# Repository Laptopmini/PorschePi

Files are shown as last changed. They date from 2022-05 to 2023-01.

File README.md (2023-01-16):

# PorschePi

RaspberryPi based custom head unit for classic Porsche. Inspired by the [Porsche Classic Communication Management (PCCM)](https://shop.porscheusa.com/porscheoem/porsche_classic_/Highlights/porsche_classic_communication_management_pccm_91164559100.html) (91164559100), featuring a much larger touchscreen and the ability to use CarPlay wirelessly.

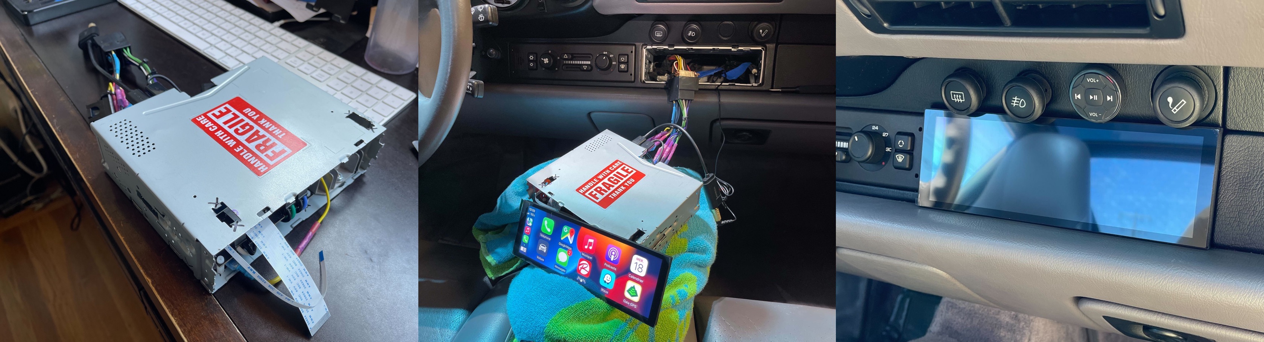
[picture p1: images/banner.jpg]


## General Information

In short, the goal was to create a single DIN head unit which fits in the rather restricted dashboard of classic Porsches without the need for any drilling, cutting or soldering (of the cabin), all the while making it look as OEM as possible. The results is a RPi 3 sandwiched between a Waveshare LCD controller and a Bang & Olufsen Hifiberry soundcard, with a graceful shutdown mechanism, powered USB hub, all fitted inside a removable single din unit.

### Key Features

- 7.9" Touchscreen
- Bang & Olufsen amplifier w/ 4 channel output
- Bluetooth remote for quick Play/Pause, Skip, Volume control
- Wireless CarPlay w/ Siri supported
- Porsche boot screen
- Porsche logo in CarPlay interface
- Porsche colored OAP interface (Black, Grey, Red)
- Graceful shutdown w/ 5 minute standby mode when ignition turn off
- 3D printed bezel

## Software

- [OpenAuto Pro v16](https://bluewavestudio.io/shop/openauto-pro-car-head-unit-solution/) ($29.99)
- [Plugin CarPlay Autobox for OpenAuto Pro](https://bluewavestudio.io/shop/plugin-carplay-autobox-for-openauto-pro/) ($9.00)
<!-- - [Plugin RTL-SDR for OpenAuto Pro](https://bluewavestudio.io/shop/plugin-rtl-sdr-for-openauto-pro/) ($6.00) -->

> TOTAL: $38.99

## Hardware

- [Raspberry Pi 3 Model B+](https://thepihut.com/products/raspberry-pi-3-model-b-plus?src=raspberrypi) ($35)
- [BeoCreate 4-Channel Amplifier](https://www.pishop.us/product/beocreate-4-channel-amplifier/) ($189.95)
- [Waveshare 7.9inch Capacitive LCD HDMI Display](https://www.amazon.com/7-9inch-Capacitive-LCD-HDMI-Resolution/dp/B087CNJYB4/) ($96.99)
- [SanDisk Extreme PRO microSDHC Memory Card Class 10](https://www.amazon.com/SanDisk-Extreme-microSDHC-Memory-Adapter/dp/B06XYHN68L/) ($13.23)
- [Carlinkit Wireless Carplay Dongle](https://www.amazon.com/Carlinkit-Wireless-Carplay-Android-Compatible/dp/B08FT73V87) ($58.99)
- [Powered USB Hub](https://www.amazon.com/Sabrent-Individual-Switches-Included-HB-UMP3/dp/B00TPMEOYM) ($18.99)
- [USB Microphone Adapter](https://www.amazon.com/UGREEN-External-Headphone-Microphone-Desktops/dp/B01N905VOY) ($13.99)
- [3.5mm TS to TRS](https://www.amazon.com/CablesOnline-2-Pack-Stereo-Adapters-AD-A37G-2/dp/B07787WMHG) ($5.95)
- [Bluetooth Media Remote Button](https://www.amazon.com/Wireless-Bluetooth-Motorcycle-Steering-Bracket/dp/B081RG3NKC) ($17.99)
- [GPIO Female to Female Jumper Wires](https://www.amazon.com/dp/B09FP1WF8Q) ($5.99)
- [12v 16AWG Cables (5ft/Color)](https://www.amazon.com/Fermerry-Silicone-Stranded-Automotive-Electronic/dp/B089CPH72F?th=1) ($15.62)
- [12v Timer Relay](https://www.amazon.com/Timer-CONFIGURABLE-CYCLING-OPTIONAL-TRIGGER/dp/B083HN673G/) ($34.99)
- [12v to 5v Stepdown](https://www.amazon.com/Regulator-Converter-12V-Waterproof-Transformer/dp/B09SD9SH8C) ($13.99)
- [SPDT Relays](https://www.amazon.com/Pack-EPAuto-Relay-Harness-Bosch/dp/B072QXDZRD/) ($10.97)
- [Heatshrink Crimp Connectors](https://www.amazon.com/TICONN-Connectors-Waterproof-Electrical-Automotive/dp/B08NWBRV4K) ($9.99)
- [T-Tap Wire Connectors](https://www.amazon.com/dp/B07XMJ5KTY) ($9.95)
- [Nylon Standoffs](https://www.amazon.com/dp/B07DPPNBFN) ($12.89)
- [Heatshrink Tubbing](https://www.amazon.com/560PCS-Heat-Shrink-Tubing-Eventronic/dp/B072PCQ2LW/) ($6.99)
- [6-Pin Ribbon Cable](https://www.amazon.com/dp/B07S19M2G1) ($6.69)
- [6-Pin Extension Connector](https://www.amazon.com/dp/B07RWNDFV1) ($7.99)
- [40-Pin Ribbon Cable](https://www.amazon.com/dp/B09CL53KZF) ($6.90)
- [Heatsinks](https://www.amazon.com/dp/B08N68V2N9) ($4.59)
<!-- - [FM Radio RTL-SDR USB Adapter](https://www.amazon.com/NooElec-NESDR-Smart-Enclosure-R820T2-Based/dp/B01HA642SW) -->

> TOTAL: $598.63

## Tools

- USB Keyboard & Mouse for setup
- DC 5V 3A Power Supply for Pi setup
- [DC 12V 5A Power Supply for Amplifier setup](https://www.amazon.com/ALITOVE-Adapter-Converter-100-240V-5-5x2-1mm/dp/B01GEA8PQA/)
- Power Drill
- Dremel Tool
- [Heat Gun](https://www.amazon.com/Portable-Handheld-Crafts-Embossing-Wrapping/dp/B08Z3GQN6X/)
- Wire Stripers
- [Crimping Tool](https://www.amazon.com/dp/B07S4HDGK9)

> The cost of tools was omitted as most were owned, borrowed or will remain after this project.

## Cost

> TOTAL: $637.62
>
> TARGET: < $1,350.10

## Resources

### BlueWave Studio

- [Supported Keystrokes](https://bluewavestudio.io/community/thread-2048.html)
- [Graceful delayed shutdown example](https://bluewavestudio.io/community/thread-1128.html)

### HiFiBerry BeoCreate

- [Setup Instructions](https://www.hifiberry.com/docs/software/configuring-linux-3-18-x/)
- [Documentation](https://www.hifiberry.com/beocreate/beocreate-doc/)
- [Support Forums](https://support.hifiberry.com/hc/en-us/community/topics/115000377385-DSP-boards-and-Beocreate)
- [Repo](https://github.com/hifiberry/hifiberry-os)
- [DSP Toolkit](https://github.com/hifiberry/hifiberry-dsp/blob/master/doc/dsptoolkit.md)

### WaveShare

- [Documentation](https://www.waveshare.com/wiki/7.9inch_HDMI_LCD)

### Timers Shop

- [Website](http://timers.shop/6V-28V-10-Amp-Timer-Wi-Fi-configurable-via-phone_p_44.html)
- [Documentation](https://timers.shop/assets/documentation/Multifunctional_Timer_Wifi.pdf)
- [Configuration Video](https://www.youtube.com/watch?v=wqbvz5oopu0&feature=emb_title)

## Setup

For the following instructions, connect a regular display and use a keyboard & mouse until you have completed the `Waveshare Touchscreen` step.

### OpenAuto

- [Flash](https://www.balena.io/etcher/) your `openauto-pro-16.0.zip` image to the SD card
- Remount & run `sh copy_helpers.sh /Volumes/boot/`
- Insert the SD Card into the Pi, and boot up the setup
- Use `1`, `2`, `UP`, `DOWN` and `ENTER` keys to work your way through the wizard

### Autobox (CarPlay)

- Once on the main screen, select `Autobox`, and `Browse`
- Go to `/boot/porschepi/` and select `openauto_autobox_plugin.zip`
- Then select `Enter serial...`, and use your plugin license key
- Select `Finish`, and from your iPhone, connect the the bluetooth device named `AutoKit-****`
- Wait for it to associate the wifi network, at which point the interface should appear
- Within CarPlay, select `Car` to return to OpenAuto

### Pi Settings

- Use [Power] -> [Exit] to reach the Pi's desktop
- Go through the "Welcome to Raspberry Pi" setup but ignore the "Set Up Screen" step for now, do NOT update packages
- Make sure SSH is enabled under the Raspberry Pi Configuration, use the command `ifconfig` to make note of the Pi's assigned IP on the network
- Under `Preferences` -> `Appearance Settings`, change the wallpaper to `/boot/porschepi/splash.png` and invert the Menu Bar's colors
- Under `Preferences` -> `Raspberry Pi Configuration`, change the hostname to `Porsche`
- Execute `cd /boot/porschepi && sudo sh apply_configs.sh` and wait for the Pi to power down

### WaveShare Touchscreen

- Connect the Waveshare touchscreen and restart the Pi
- If you still need to adjust your screen orientation, do the following
  - [Power] -> [Exit] out of OpenAuto
  - Go to `Screen Configuration`, `Configure`, `Screens`, `HDMI-1`, `Orientation`
  - Using the "Rotate Touch" button behind the screen, press until you see a green flash to rotate the touch. Repeat as necessary.

### Bluetooth Remote

- Press any button on the bluetooth remote, it should start blinking
- From the Pi's desktop, go to `Preferences` -> `Bluetooth Manager`
- In the list of devices, select `Jetion remote v2.0`
- Under `Device`, select `Pair` then `Trust`

### BeoCreate

- Refer to `beocreate/docs/jumpers.png` and remove jumper 4 & 5 on the Beocreate HAT.
- Refer to `beocreate/docs/connectors.png` to know how to wire in the soundcard to your speakers
- Connect the Pi to the BeoCreate HAT and power it up using the 12v input
- Lower the volume in OpenAuto (or from the Pi's Sound Preferences) to avoid damaging your speakers when first testing
- Execute `cd /boot/porschepi/beocreate && sudo sh setup.sh`

### Create a Backup

- Make an image of your SD card using `sudo dd bs=4m if=/dev/disk2 of=builds/porschepi-X.Y.Z.img`
- Reflash this image anytime to a similar sized SD card to restore this setup

## Assembly

### Diagram

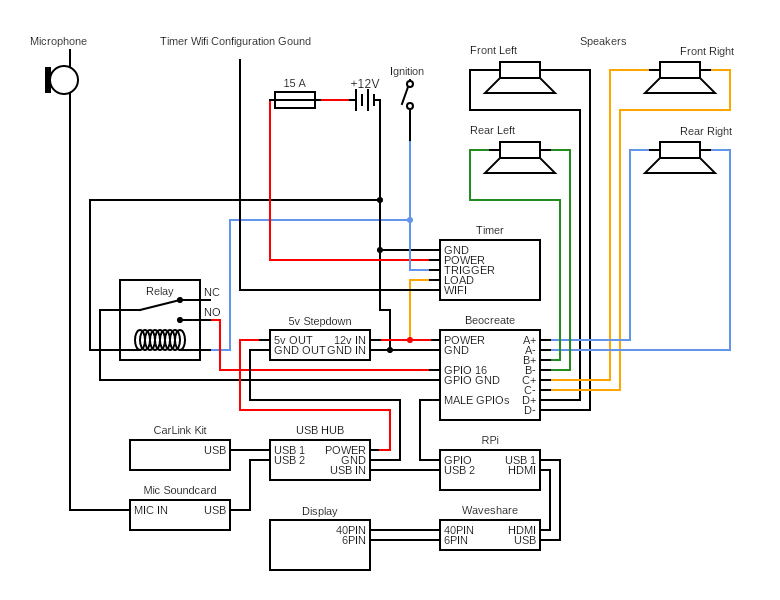
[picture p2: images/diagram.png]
PorschePi Diagram (https://www.circuit-diagram.org/editor/c/6b1c75bd69934876a32e00b4504df468)


### Form

First, you need to separate the screen from its PCB carefully using a knife. I recommend you disconnect its ribbons and tape them safely out of the way to avoid damaging them. Once done, upgrade to the longer ribbons to provide more working room between the board and display.

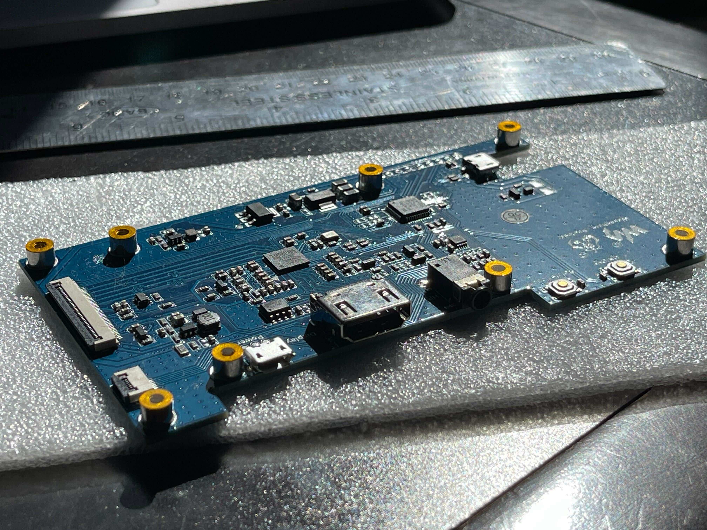
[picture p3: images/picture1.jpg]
Picture of separated PCB


I recommended you bench test components independently before mounting them. Keep in mind to space out components which produce heat, such as the PCB stack from other parts. Use heatsinks to help dissipate the heat from the PCB stack.

For the timer, temporarily wire it to a power source according to the previous schematics, and ground the white wire while you power it on to enable wifi configuration. Connect to its network and visit the IP listed on the timer. Import the configuration `timer/configuration.bin`, or set it to Function 12 with a timer t1 of 5 minutes and trigger value of 2. As seen in the diagram, its recommended you make this configuration wire output from your unit; you can then add a T-tap (or similar) to your ground wire to easily connect it at any time to make adjustments to its configuration.

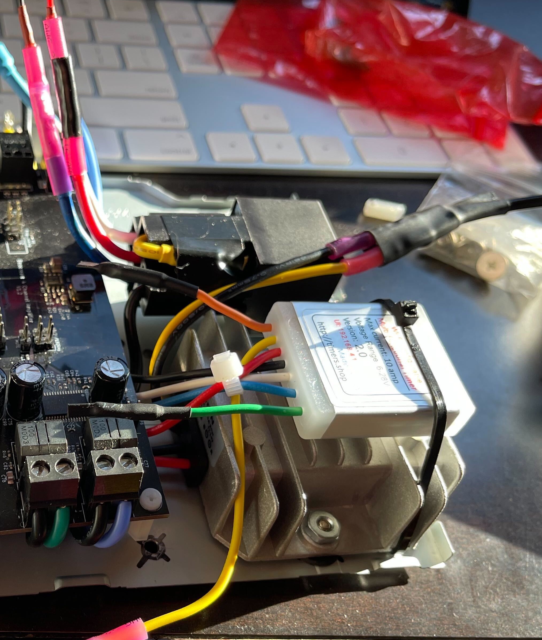
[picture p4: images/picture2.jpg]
Picture of timer wired in


To test or wire in the automotive relay (to monitor the state of the ignition), enable the power monitoring by setting `POWER_MONITOR_ENABLED=1` in `/boot/porschepi/settings.conf`. When ignition is cutoff, the screen and sound is turned off during a grace period at the end of which the system is shutdown. If ignition is restored, the screen and sound are re-enabled and any shutdown canceled. The script is setup to use GPIO / BCM 16 - physical pin 32 on Beocreate GPIO. This allows the use of the neighboring ground on pin 34, as seen below.

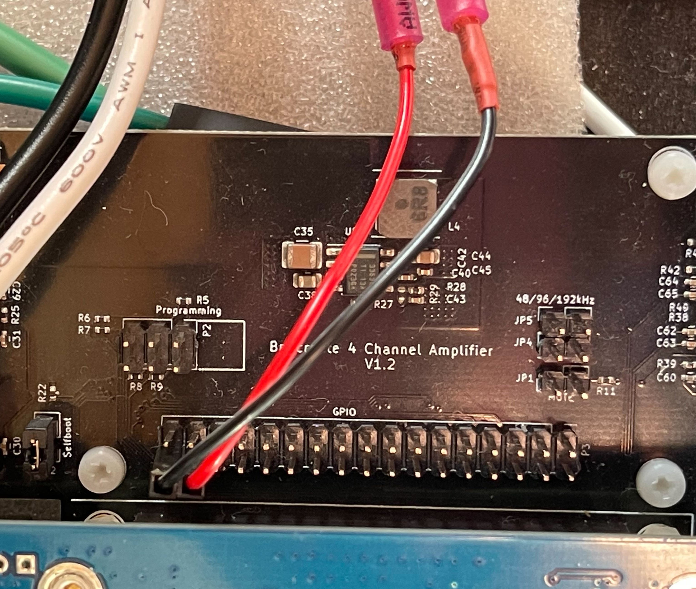
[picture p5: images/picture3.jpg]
Picture of relay wired in


### Fit

As with the PCCM, one of the goals of this project is to fit into a standard single DIN format. After finding an old unit, take it apart and gut out its components to reuse the shell as a donor for your new hardware.

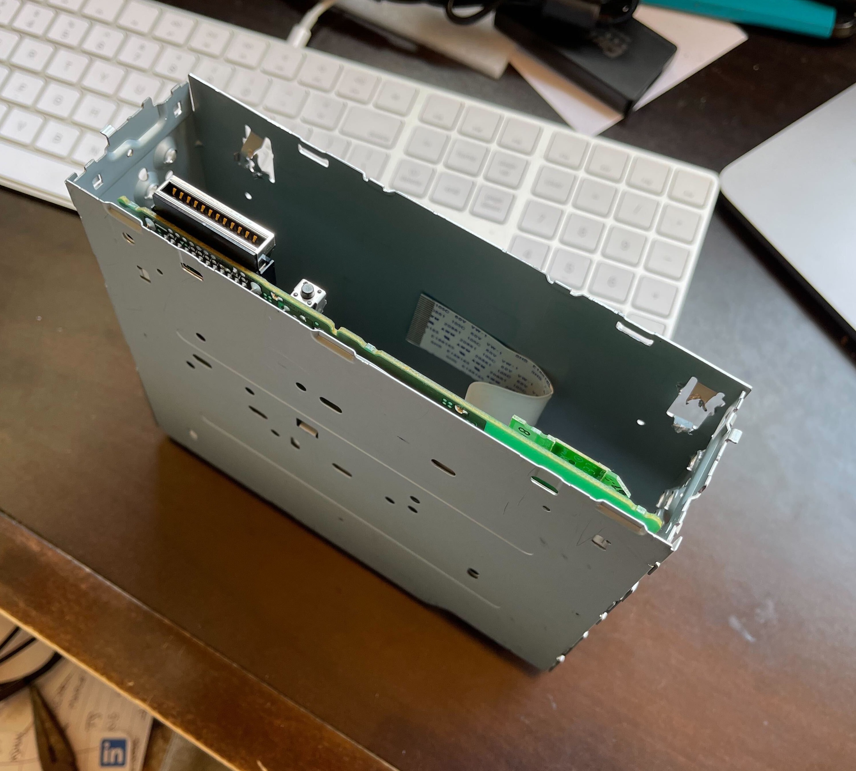
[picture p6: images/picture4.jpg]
Picture of shell


Using the previously mentioned diagram, arrange the components within the shell accordingly. Using a Dremel tool, you can clean up mounting points and cut out any conflicting parts of the shell.

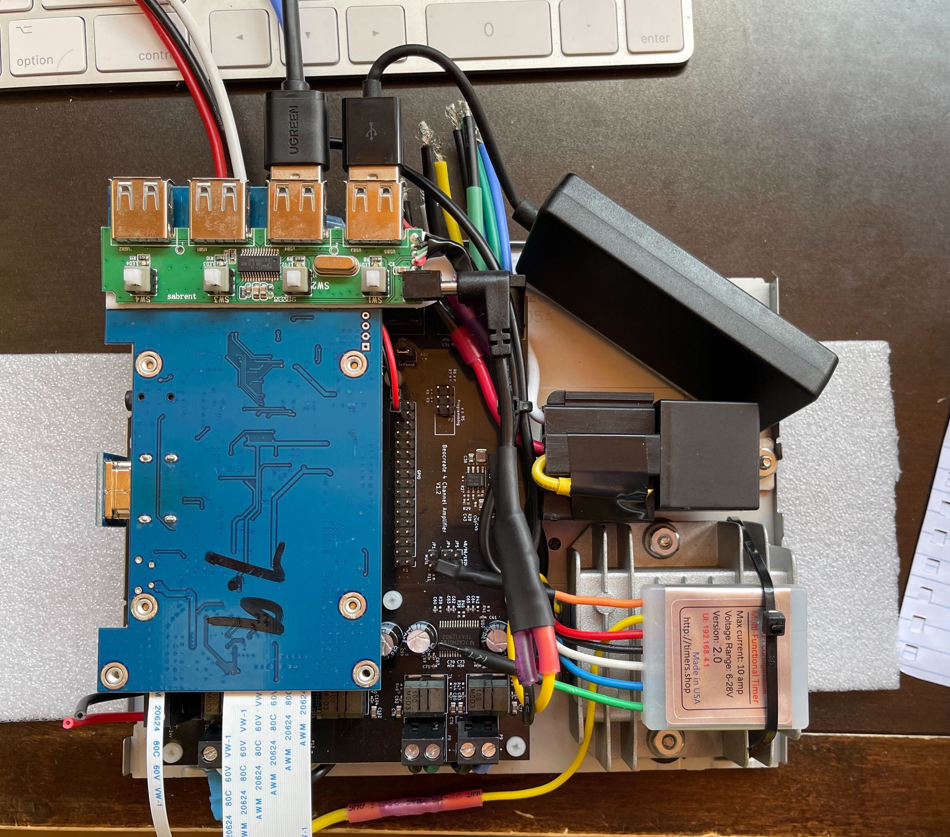
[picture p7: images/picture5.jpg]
Picture of shell with all components mounted in


Once the unit is completed, wire it into the harness used to connect the head unit to the car. Optionally, you can add a 15AMP fuse onto the positive power input to insulate your unit from other components relying on your vehicle's existing fuse.

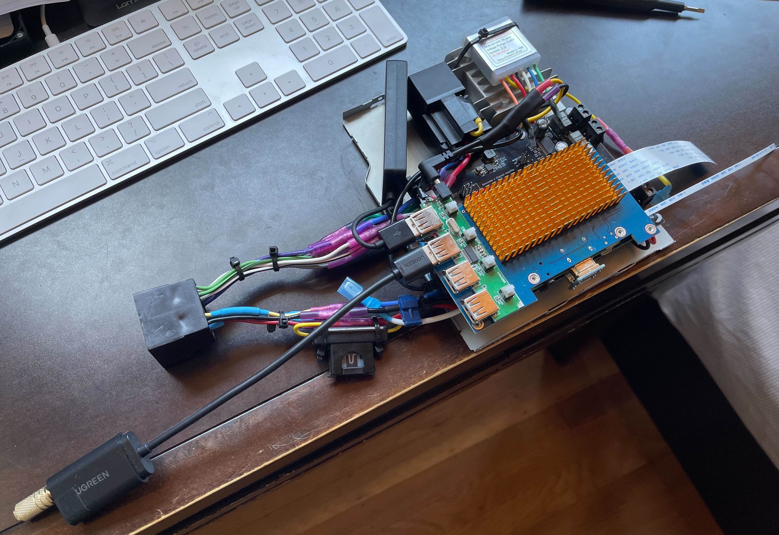
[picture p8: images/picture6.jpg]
Picture of harness wired in


### Finish

As a safety measure, remove the fuse corresponding to the head unit in your car, then connect the harness before reapplying the fuse. Verify that all functions are working before proceeding with inserting the unit into the dashboard.

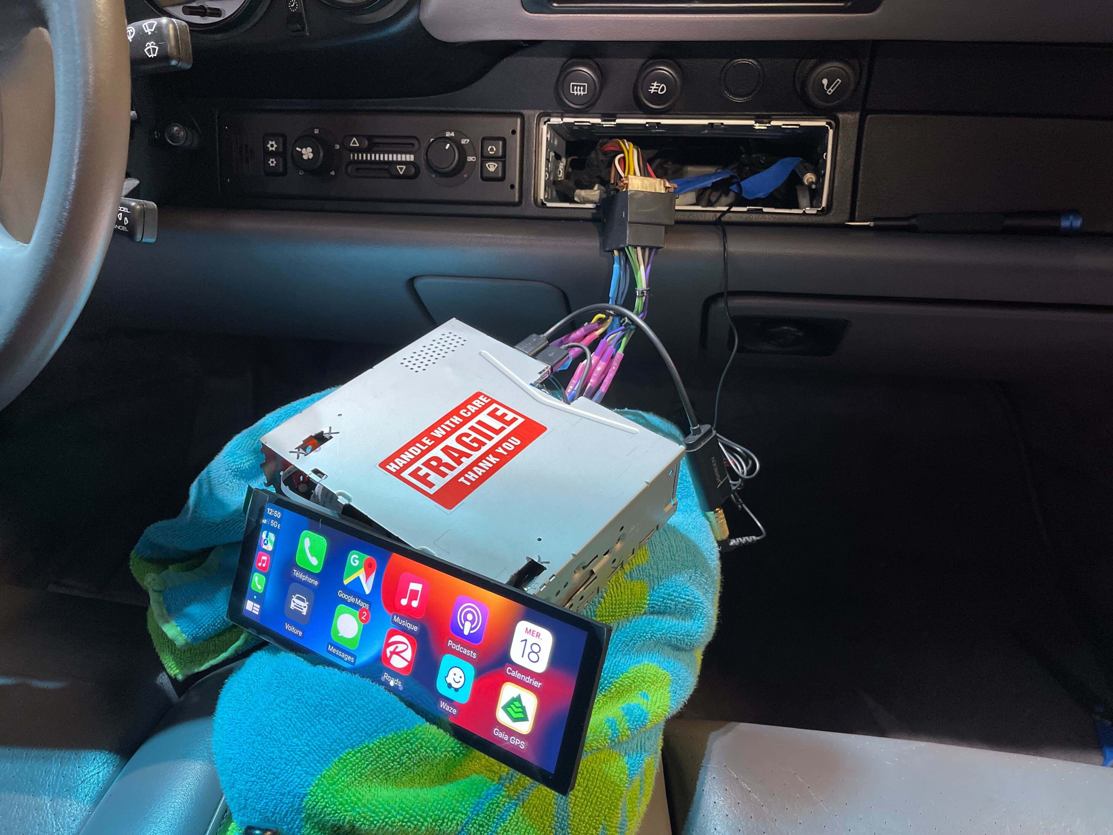
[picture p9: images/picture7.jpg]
Picture of unit testing in car


If you run into issues, check out the Troubleshooting section below for some common issues. Once you've verified your setup, insert the unit into the dashboard carefully, making sure wires behind it are clearing any obstructions and not getting pinched. You can access the back of the unit through the underside of the dashboard. Don't forget to mount the bluetooth remote as well.

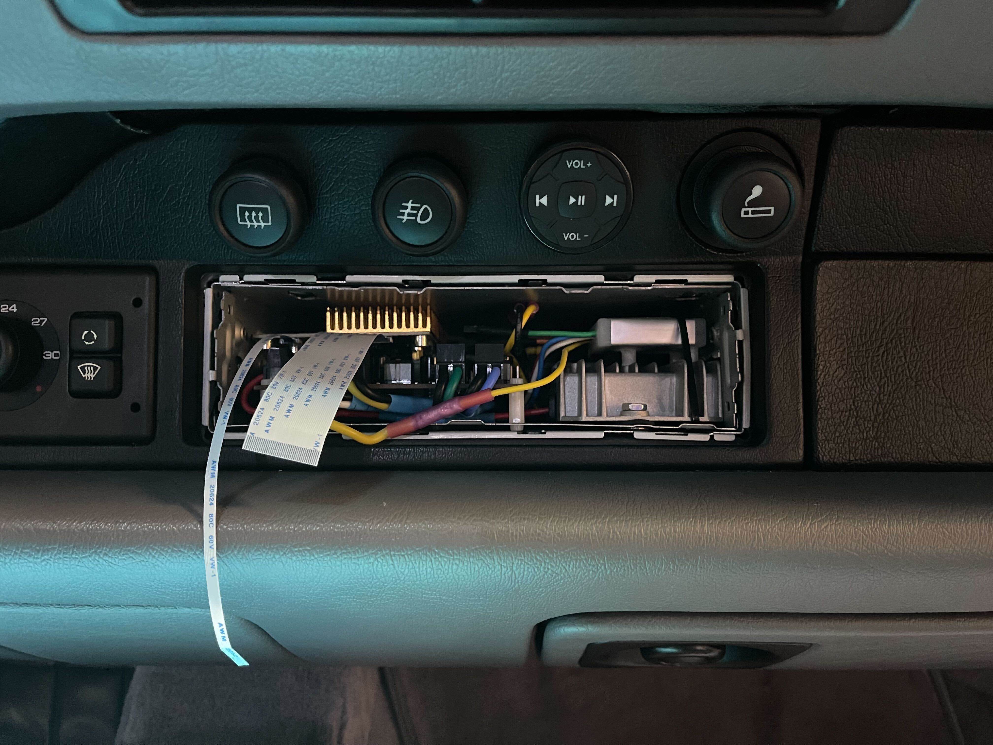
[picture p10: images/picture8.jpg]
Picture of unit in car


Given my limited experience with 3D printing, I enlisted the help of a friend to design and print a bezel for the screen with mounting tabs to secure it to the dashboard. Use the `waveshare/bezel.STL` file to print your own copy. If you don't own a 3D printer, I recommend using an online printing service.

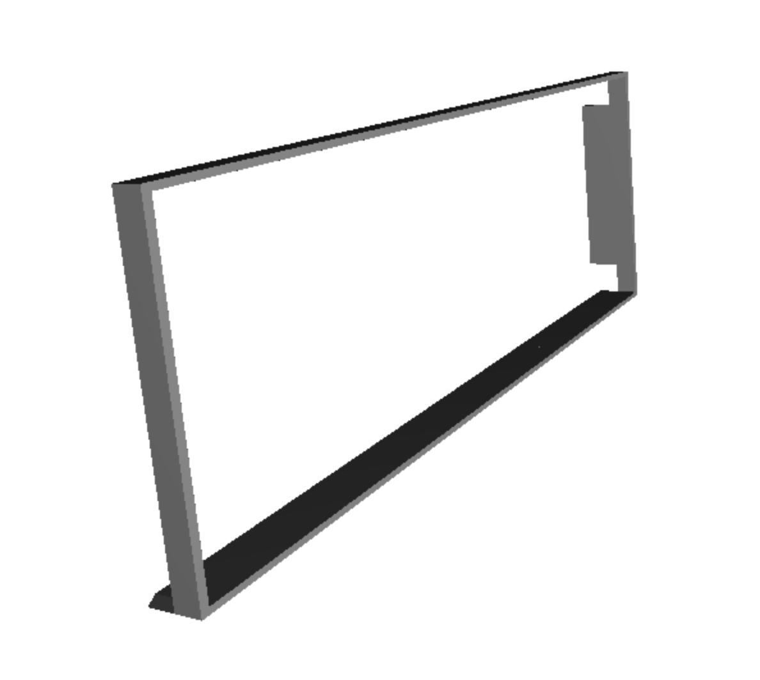
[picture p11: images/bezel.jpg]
3D Printed Bezel


Insert the screen into the 3D printed bezel and then push its tabs into the slits of the dashboard to securely mount it. Make sure the first insert the top then bottom, as to clear the instrument knobs located above the head unit.

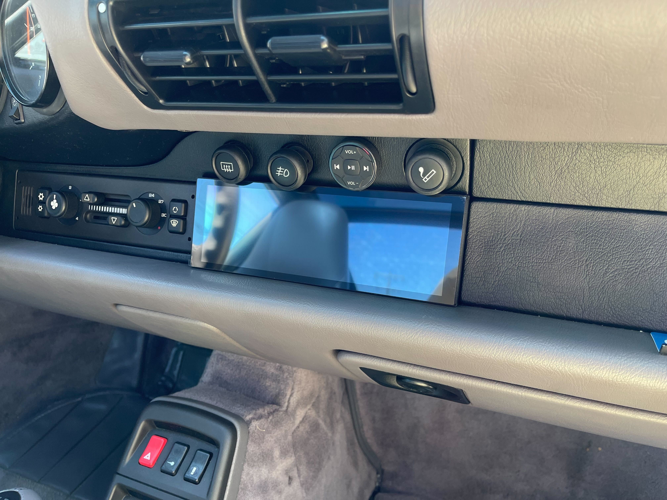
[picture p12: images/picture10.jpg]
Picture of screen mounted


## Troubleshooting

### System Logs

You can find logs for OpenAuto under `/home/pi/.openauto/cache/openauto.log`.

### CarPlay

If you need to reset your CarPlay connection on your device, go to Settings.app, and forget both Bluetooth and Wifi networks for `AutoKit-****`. Then reconnect via bluetooth to re-initiate the pairing process.

### Display

If you see black borders around the screen, try disabling `disable_overscan=1` and adapting the `overscan_*` properties in `/boot/config.txt`.

### Splash

To make a new splash screen based on a sequence of 24 images use the following command:

```bash
ffmpeg -r 24 -f image2 -s 1280x400 -i rpi/splash_%01d.png -start_number 1 -vframes 24 -vcodec libx264 -crf 25 -pix_fmt yuv420p splash.h264
sudo cp -f ~/splash.h264 /usr/share/openautopro/splash1.h264
sudo cp -f ~/splash.h264 /usr/share/openautopro/splash2.h264
```

### Custom Keys

To add keymaps, use `DISPLAY=:0.0 xev` to find the correct keycode and add mappings to `/boot/porschepi/restore-settings.sh` using `xmodmap`.

### Volume

To change the default volume of the amplifier (not the default software volume), change the value of `VOLUME` in `/boot/porschepi/settings.conf`. Adjust this according to what your speakers can handle.

When using the Bluetooth Remote, if the volume is lowered or raised too fast repetitively, the left and right channel can become unbalanced (different volume) due to a bug. If this occurs, use the "Reset Volume" application in OpenAuto.

### Power Monitor

If you run into issues with the power monitoring service, you can check its status using `systemctl status power-monitor.service` or disable its operation using `POWER_MONITOR_ENABLED=0` in `/boot/porschepi/settings.conf`. To check the service's logs run `journalctl -u power-monitor.service` and use `POWER_MONITOR_DEBUG=1` to make it print out debug statements.

If you ever make changes to the Timer's power cutoff timing, make sure to adjusts the `SHUTDOWN_DELAY` accordingly in `/boot/porschepi/power-monitor.py`. The value of `SHUTDOWN_DELAY` should always be smaller than that of the timer, with enough time to allow for a graceful shutdown before power is cutoff.

## Omitted Components

Here is a list of components which were considered at some point but omitted in the end for one reason or another:

- [Raspberry Pi 4 Model B 2019 Quad Core 64 Bit WiFi Bluetooth (4GB)](https://www.amazon.com/Raspberry-Model-2019-Quad-Bluetooth/dp/B07TC2BK1X)
  - Unable due to shortage
- [CarPiHat](https://thepihut.com/products/carpihat-car-interface-hat-for-raspberry-pi?variant=41600908492995)
  - Incompatible with 4-Channel Amplifier HAT
- [ELM327 OBD to USB Adapter](https://www.amazon.com/gp/product/B083FML519/)
  - Poor access to OBD in car, impractical with little reward

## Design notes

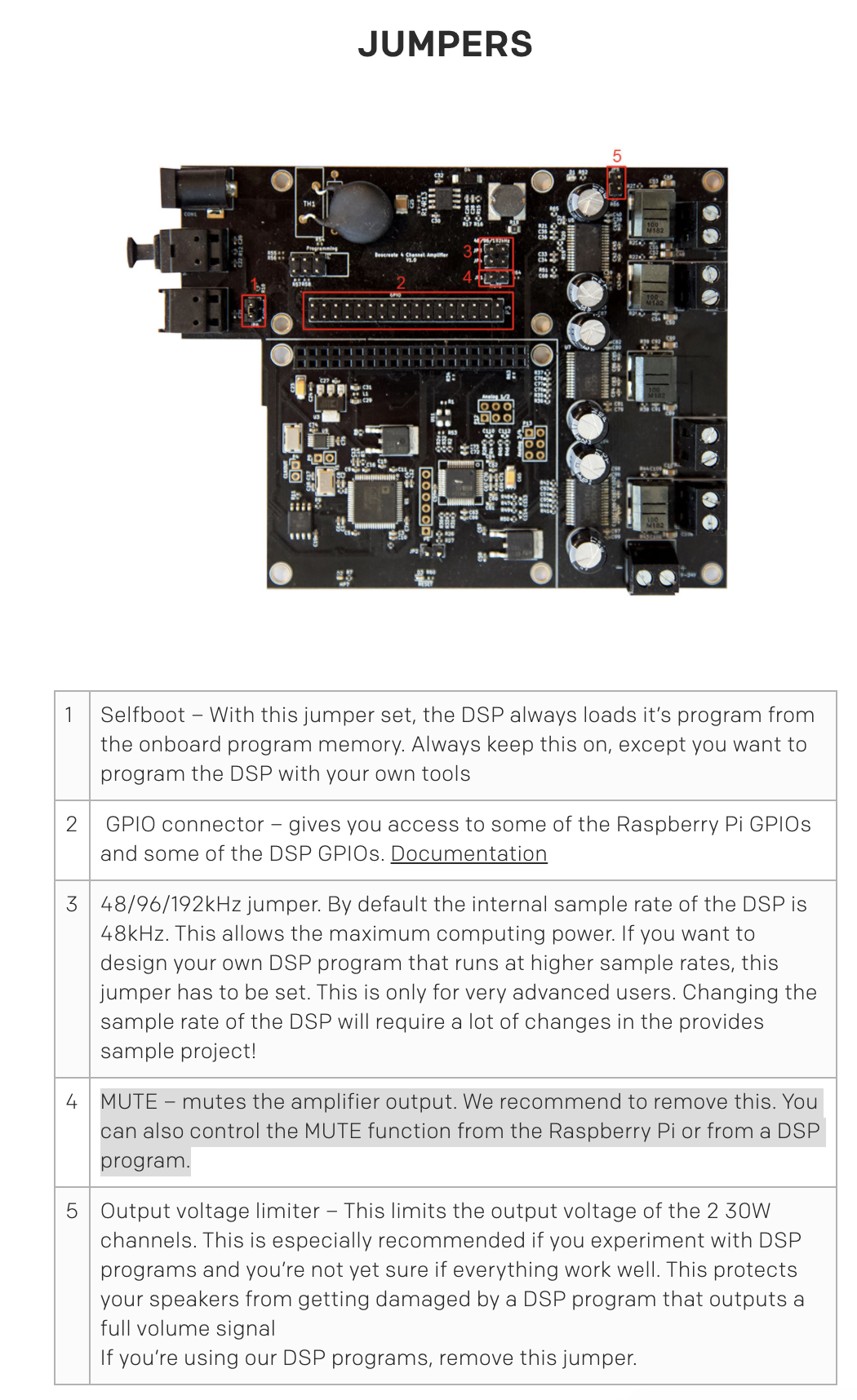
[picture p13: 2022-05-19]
beocreate/docs/jumpers.png

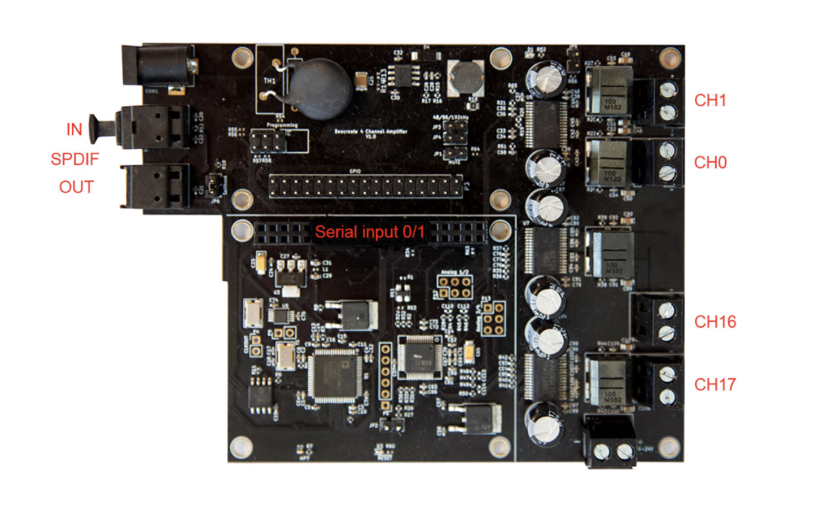
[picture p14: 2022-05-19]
beocreate/docs/dspchannels.png

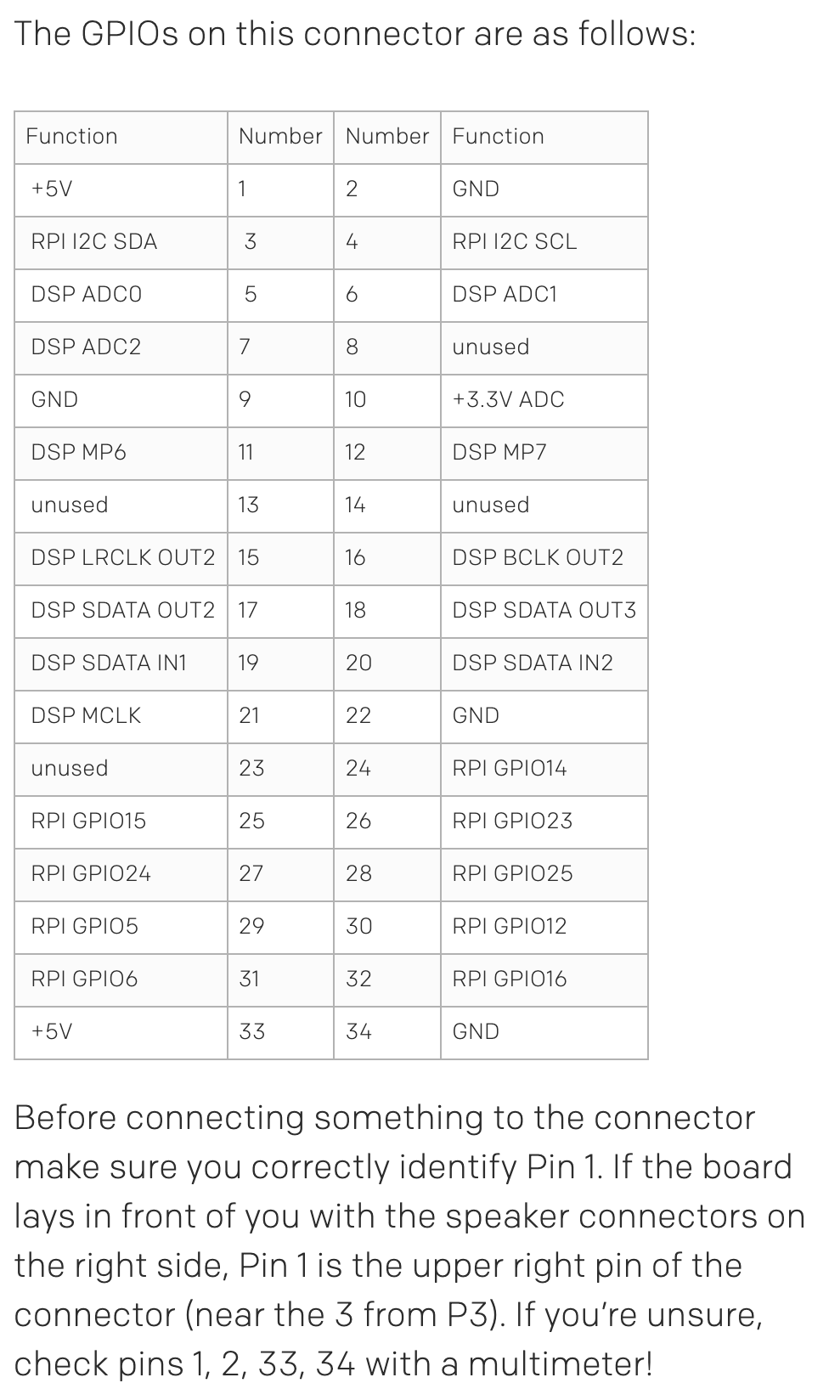
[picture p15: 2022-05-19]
beocreate/docs/available-gpio.png

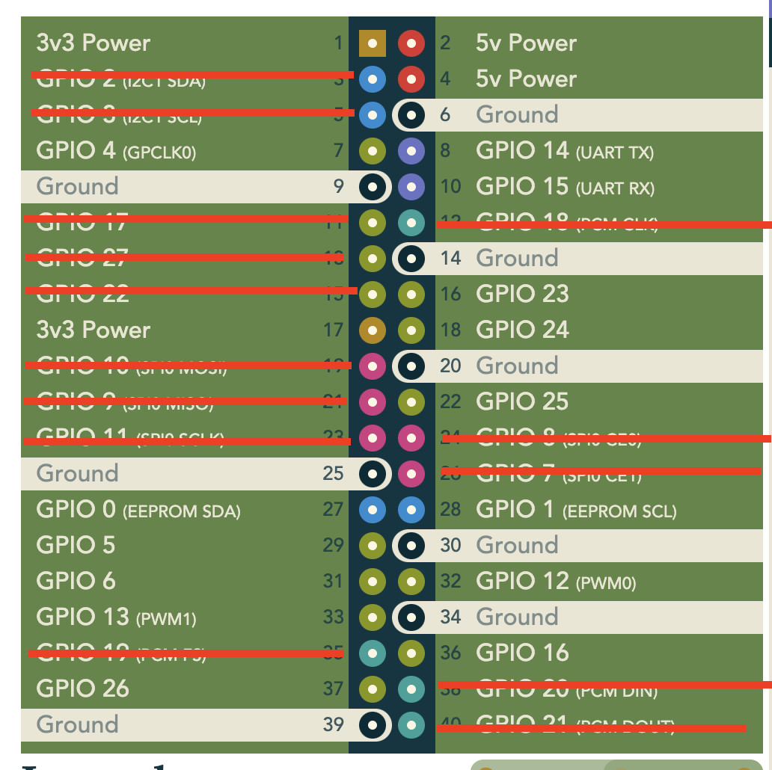
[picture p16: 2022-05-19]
beocreate/docs/available-gpio-pi.png

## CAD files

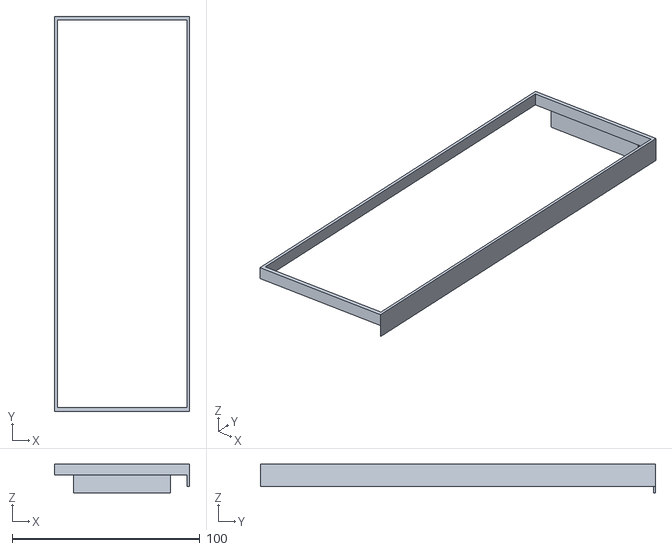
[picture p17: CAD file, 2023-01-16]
waveshare/bezel.STL
71.9 x 210.3 x 15.4

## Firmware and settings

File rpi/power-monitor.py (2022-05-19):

#!/usr/bin/python3 -u
# Source: https://bluewavestudio.io/community/thread-1128.html
# This script was originaly written by 765GHF, many thanks to them.

import os
import RPi.GPIO as GPIO
import subprocess
import sys
import time
from dotenv import load_dotenv

# Configuration File
CONF = "/boot/porschepi/settings.conf"

# Load configuration
load_dotenv(CONF)

if not int(os.getenv("POWER_MONITOR_ENABLED", "0")):
	print("Power monitoring disabled in " + CONF + ". Terminating.")
	sys.exit() 

# Enable debug verbose output
DEBUG = int(os.getenv("POWER_MONITOR_DEBUG", "0"))

# GPIO / BCM 16 - physical pin 32 on Beocreate
PORT = 16

# Shutdown delay in seconds (4.5 mins)
SHUTDOWN_DELAY = 270

# Number of seconds after ignition returns to cancel shutdown
CANCEL_SHUTDOWN = 5

# specify pin numbering format
GPIO.setmode(GPIO.BCM)

# set pin to input, set pull up resistor so it reads high
GPIO.setup((PORT), GPIO.IN, pull_up_down=GPIO.PUD_UP)

IGN_STATUS = 1
SHUTDOWN = 0
IGN_OFF_TIME = 0
IGN_OFF_LAST_SEEN = 0
NOW = 0

def setDisplayEnabled( on ):
	ARG = "on"
	if not on:
		ARG = "off"
	try:
		subprocess.run("XAUTHORITY=/home/pi/.Xauthority xset -display :0.0 dpms force " + ARG, shell=True)
	except subprocess.CalledProcessError as displaycmd:
		print("Turning ", ARG, " display failed with error code: ", displaycmd.returncode)
	return

def setSoundEnabled( on ):
	CMD = "unmute"
	if not on:
		CMD = "mute"
	try:
		subprocess.run(["/opt/hifiberry/bin/" + CMD + "-beocreate"])
	except subprocess.CalledProcessError as soundcmd:
		print("Attempt to ", CMD, " sound failed with error code: ", soundcmd.returncode)
	return

# Make sure Sound & Display are enabled
setSoundEnabled(True)
setDisplayEnabled(True)

while True:
	NOW = time.time()

	# Get the status of the ignition
	IGN_UP = GPIO.input(PORT)
 
	# Ignition switched off? Then set shutdown flag and igntion off time
	if not IGN_UP and not SHUTDOWN:
		print("Ignition switched off, setting shutdown flag!")
		SHUTDOWN = 1
		IGN_OFF_TIME = NOW
		setSoundEnabled(False)
		setDisplayEnabled(False)

	# Increment this counter while ignition is off
	if not IGN_UP and SHUTDOWN:
		IGN_OFF_LAST_SEEN = NOW

	# If ignition is off, check if shutdown delay time reached
	if (SHUTDOWN and not IGN_UP and ((NOW - IGN_OFF_TIME) > SHUTDOWN_DELAY)):
		print("Shutdown delay of", SHUTDOWN_DELAY, "seconds reached, shutting down!")
		try:
			subprocess.check_output(["shutdown", "-h", "now", "--no-wall"])
		except subprocess.CalledProcessError as shutdowncmd:
			print("Shutdown failed with error code: ", shutdowncmd.returncode)
			break
	
	# Cancel shutdown if power has been back for CANCEL_SHUTDOWN seconds
	if ((NOW - IGN_OFF_LAST_SEEN) >= CANCEL_SHUTDOWN ) and SHUTDOWN:
		print("Ignition has been back for ", CANCEL_SHUTDOWN, " seconds, shutdown flag reset.")
		SHUTDOWN = 0
		IGN_OFF_TIME = 0
		IGN_OFF_LAST_SEEN = 0
		setSoundEnabled(True)
		setDisplayEnabled(True)

	if DEBUG:
		STATUS = GPIO.input(PORT)
		print("Pin status is: ", STATUS)
		print("IGN_UP is set to: ", IGN_UP)
		print("SHUTDOWN is set to: ", SHUTDOWN)
		if SHUTDOWN:
			print("Igntion off time is: ", IGN_OFF_TIME)
			print("Igntion off last seen time is: ", IGN_OFF_LAST_SEEN)
			print("Current time is: ", NOW)
			print("Elapsed time is: ", (NOW - IGN_OFF_TIME))

	time.sleep(1)

if DEBUG:
	print("Exiting")

GPIO.cleanup()

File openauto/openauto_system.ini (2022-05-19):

[Units]
ConsumptionUnit=0
DistanceUnit=0
TemperatureUnit=1
[Appearance]
TimeFormat=0
ShowTopBarInAndroidAuto=true
ShowTemperature=false
ShowClockInMirroring=true
ShowClockInAutobox=false
ShowClockInAndroidAuto=true
ControlsOpacity=75
FontScale=0
Language=English
ObdBarDisplayMode=1
ShowClock=true
TileStyle=0
[System]
AndroidAutoAutostart=true
TouchscreenType=1
ScreenType=1
ScreenSplitPercentage=30
DownloadCoverart=true
[Mirroring]
ShowTopBarInMirroring=true
ResolutionWidth=1280
ResolutionHeight=400
[Autobox]
ShowTopBarInAutobox=false
ScreenDPI=160
Name=Autobox-OAP
OemName=Porsche
AutomaticWirelessConnection=true
WorkMode=2
VendorId=4884
ProductId=5408
[DayNight]
OpenAutoDayNightControllerType=2
AndroidAutoDayNightControllerType=2
AutoboxDayNightControllerType=2
SunriseTime=6:0
SunsetTime=18:0
LightSensorThreshold=100
LightSensorDescriptor=/dev/i2c-3
LightSensorAddress=57
LightSensorMinRange=0
LightSensorMaxRange=30000
OpenAutoDayNightMode=1
AndroidAutoDayNightMode=2
AutoboxDayNightMode=2
GpioPin=1
[Day]
WallpaperPath=
WallpaperMode=0
WallpaperOpacity=100
BackgroundColor=#4b4b4b
HighlightColor=#1f85ff
ControlBackground=#e2e2e2
ControlForeground=#1f85ff
NormalFontColor=#000000
SpecialFontColor=#000000
DescriptionFontColor=#202020
BarBackgroundColor=#b2b2b2
ControlBoxBackgroundColor=#808080
GaugeIndicatorColor=#f5b42a
IconShadowColor=#60000000
IconColor=#000000
SideWidgetBackgroundColor=#b2b2b2
BarShadowColor=#333333
[Night]
WallpaperPath=
WallpaperMode=0
WallpaperOpacity=100
BackgroundColor=#4b4b4b
HighlightColor=#d5001c
ControlBackground=#000000
ControlForeground=#d5001c
NormalFontColor=#ffffff
SpecialFontColor=#d5001c
DescriptionFontColor=#888888
BarBackgroundColor=#000000
ControlBoxBackgroundColor=#181818
GaugeIndicatorColor=#d5001c
IconShadowColor=#80000000
IconColor=#ffffff
SideWidgetBackgroundColor=#000000
BarShadowColor=#333333
[General]
HandednessOfTraffic=0
ShowClock=true
HasTouchscreen=true
TemperatureSensorDescriptor=
[Video]
FPS=2
Resolution=1
ScreenDPI=140
MarginWidth=0
MarginHeight=0
ProjectionOrientation=3
[Audio]
MusicAudioChannelEnabled=true
SpeechAudioChannelEnabled=true
SplashFilePath=
PhoneNotificationFilePath=
RingtoneFilePath=
VolumeStep=1
MixerName=
MuteMixerName=
Autoplay=false
MediaStorageMusicVolumeLevel=100
[Bluetooth]
AdapterType=0
RemoteAdapterAddress=
[Obd]
ObdAdapterStartupSequence=ATZ;ATE0;ATS0;ATL0;ATH0;ATSP0
ObdAdapterDescriptor=
ObdAdapterBaudrate=115200
ObdProbePeriod=5
ObdDeviceType=0
ObdAdapterRfCommAddress=
ObdAdapterRfCommChannel=1
ObdMaxNoDataResponseCount=20
[RearCamera]
DeviceDescriptor=v4l2:///dev/video0
GpioPin=0
ShowGuideLine=false
Orientation=0
ScriptPath=
BackendType=0
ResolutionWidth=1280
ResolutionHeight=400
ViewFinderIndex=0
VolumeLevelEnabled=false
VolumeLevel=70
[Gestures]
VolumeGestureEnabled=0
SensorDescriptor=
Enabled=false
InactivityTimeout=0
SensorOrientation=3
NextTrackGestureEnabled=true
PreviousTrackGestureEnabled=true
AnswerCallGestureEnabled=true
HangUpCallGestureEnabled=true
VolumeUpGestureEnabled=true
VolumeDownGestureEnabled=true
TogglePlayGestureEnabled=true
[Wireless]
HotspotEnabled=false
Enabled=false
Ssid=Porsche
Bssid=
Key=993
Port=5000
HotspotBand=0
[Media]
DefaultStoragePath=/media
[Api]
EndpointListenPort=44405
MaxClients=3
[FM]
BandwithType=0
SquelchLevel=350
SquelchLimit=10

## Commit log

2022-05-19 feat: Initial commit
    [config.txt]
2023-01-16 fix: Added bezel file & updated README
    [bezel.STL]
